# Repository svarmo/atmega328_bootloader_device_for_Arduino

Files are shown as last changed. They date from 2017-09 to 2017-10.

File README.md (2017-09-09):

# Overview
The objective of this project is to create a fully functional Arduino Bootloader for the ATMega328 MCU.

This project will include all the sources to manufacture the programmer device, it includes the 3D printed model, the PCB manufacturing files as well as the source code for the device.

# License
This project is licenses under an MIT license, view attached file for more detail.

The MCU is works using Arduino and **HEAVILY** relies on code provided by Nick Gammon's Arduino_sketch code: https://github.com/nickgammon/arduino_sketches (Also MIT license)

All the hardware is designed by me and falls under **Open Hardware** spec so feel free to use, modify as you see fit.

## Special contributors
* Ricardo Rodriguez
* Nick Gammon

# Usage
TODO: Populate how to use

# Notes
At this point, a good write looks like this:

```
Started
Waiting 2 seconds
Attempting to enter ICSP programming mode ...ok

Getting signature
Processor = ATmega328P

*CURRENT FUSE VALUES*
Low_Fuse = E2
High_fuse = DA
Ext_Fuse = FD
Lock_Fuse = EF
Clock_Calibration_Fuse = 96

Using Lilypad 8 MHz loader.

Bootloader address = 7800
Bootloader length = 1932

*NEW FUSE VALUES*
Low_Fuse = E2
High_Fuse = DA
Ext_Fuse = 5
Lock_Fuse = 2F
Erasing chip ...
Writing bootloader ...
Written.
Verifying ...
No errors found.

Writing fuses ...

*CURRENT FUSE VALUES*
Low_Fuse = E2
High_fuse = DA
Ext_Fuse = FD
Lock_Fuse = EF
Clock_Calibration_Fuse = 96

Done.
Programming mode off.
```

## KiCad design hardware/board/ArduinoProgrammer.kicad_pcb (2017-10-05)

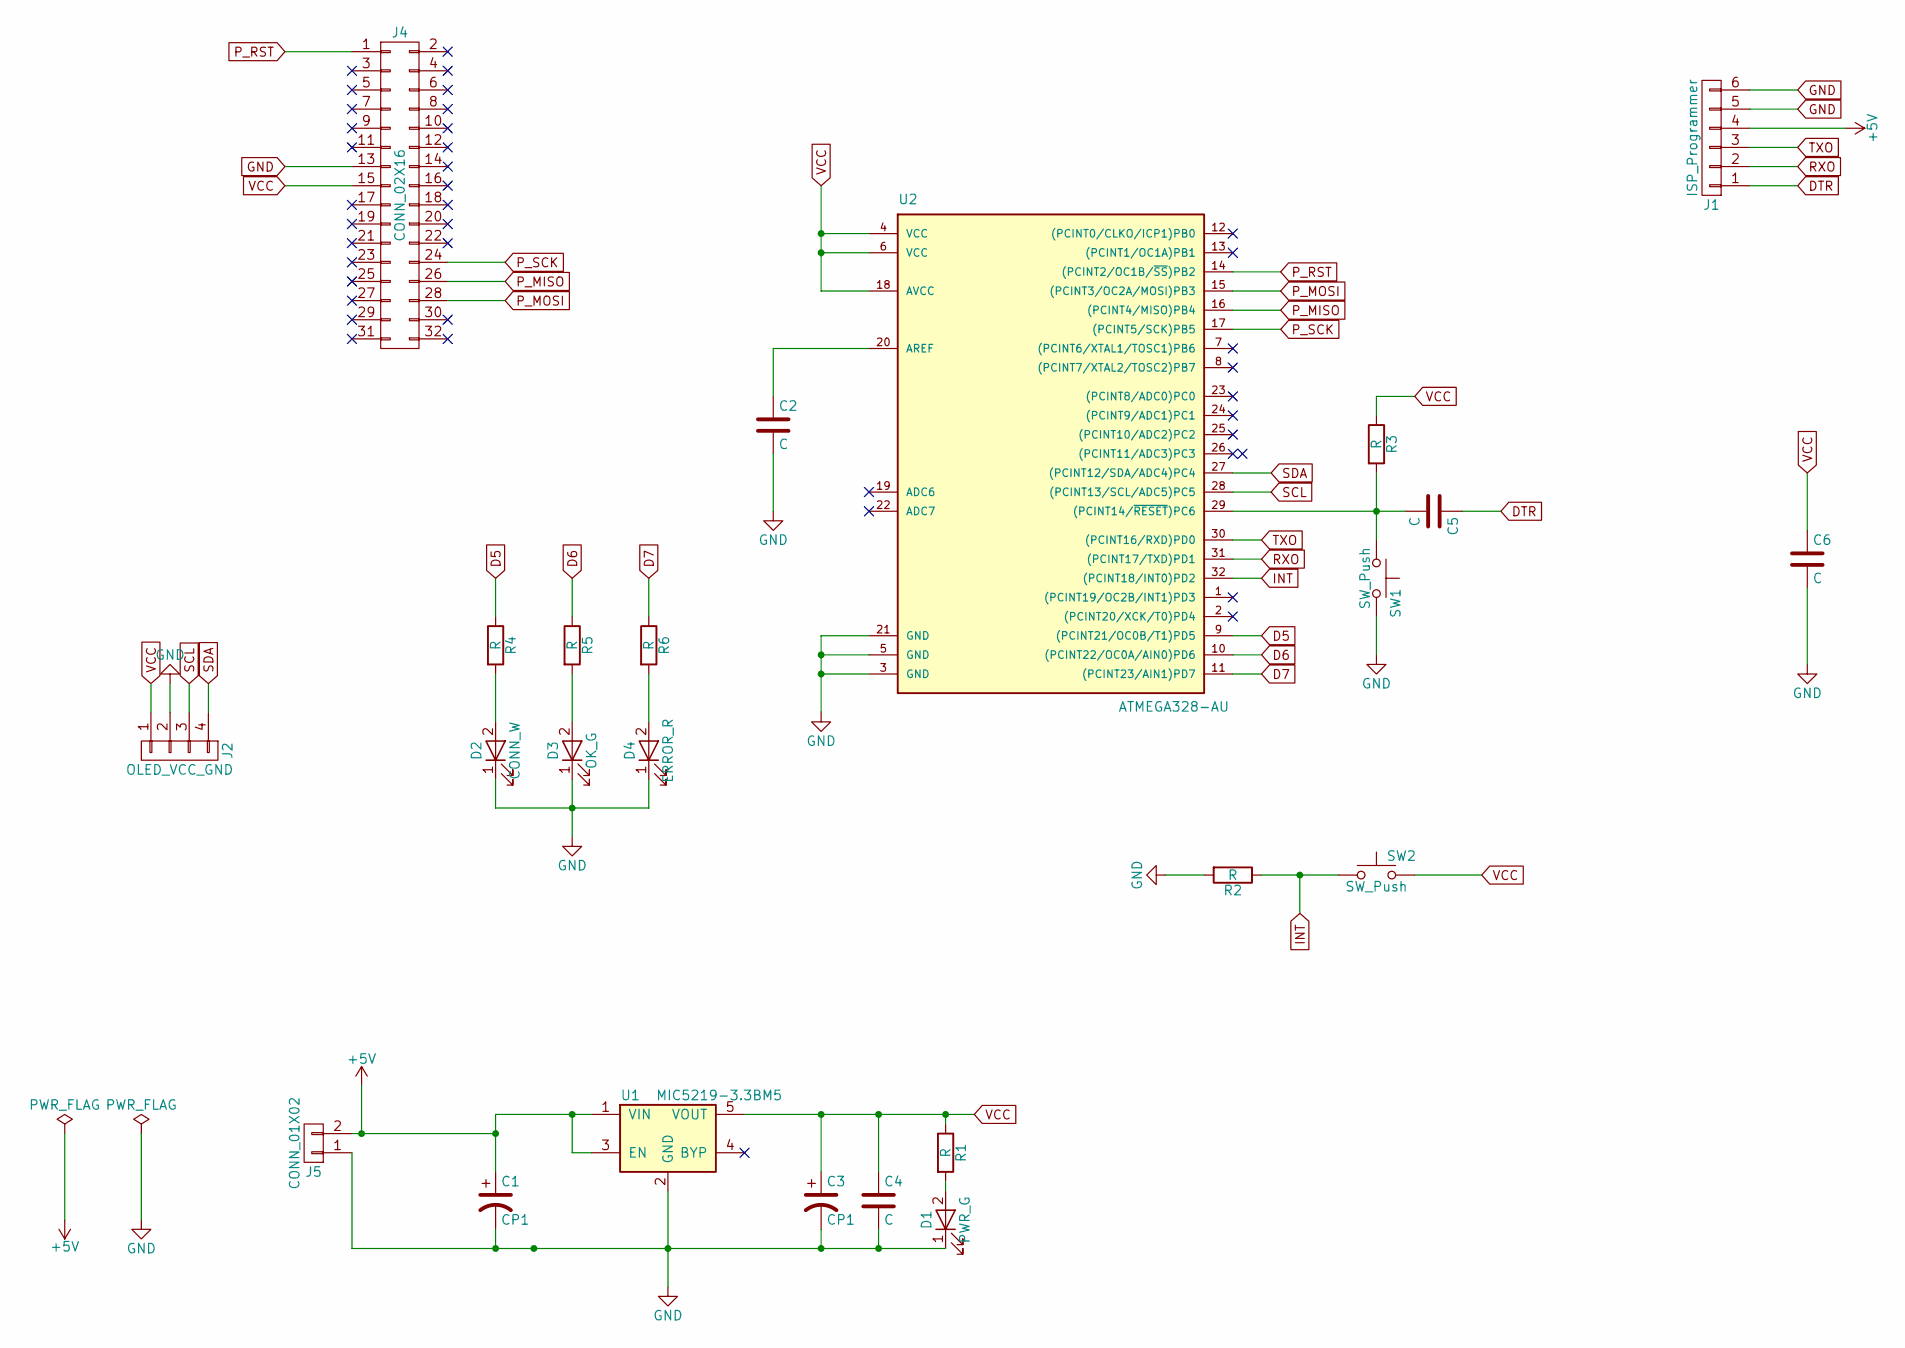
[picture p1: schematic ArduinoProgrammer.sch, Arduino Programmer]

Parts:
C1, C3: CP1; CP_Tantalum_Case-A_EIA-3216-18_Reflow
C2, C4, C5, C6: C; C_0805
D1: PWR_G; LED_0805
D2: CONN_W; LED_0805
D3: OK_G; LED_0805
D4: ERROR_R; LED_0805
J1: ISP_Programmer; Pin_Header_Straight_1x06_Pitch2.00mm
J2: OLED_VCC_GND
J4: CONN_02X16; ProgSocket
J5: CONN_01X02; Pin_Header_Straight_1x02_Pitch2.00mm
R1, R2, R3, R4, R5, R6: R; R_0805
SW1, SW2: SW_Push; SW_SPST_FSMSM
U1: MIC5219-3.3BM5; SOT-23-5
U2: ATMEGA328-AU; TQFP-32_7x7mm_Pitch0.8mm

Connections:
+5V: C1.1, J1.4, J5.2, U1.1 (VIN), U1.3 (EN)
D5: R4.1, U2.9 ((PCINT21/OC0B/T1)PD5)
D6: R5.1, U2.10 ((PCINT22/OC0A/AIN0)PD6)
D7: R6.1, U2.11 ((PCINT23/AIN1)PD7)
DTR: C5.1, J1.1
GND: C1.2, C2.2, C3.2, C4.2, C6.2, D1.1 (K), D2.1 (K), D3.1 (K), D4.1 (K), J1.5, J1.6, J2.2 (GND), J4.13, J5.1, R2.2, SW1.2, U1.2 (GND), U2.3 (GND), U2.5 (GND), U2.21 (GND)
INT: R2.1, SW2.1, U2.32 ((PCINT18/INT0)PD2)
unnamed: C2.1, U2.20 (AREF)
unnamed: C5.2, R3.2, SW1.1, U2.29 ((PCINT14/~RESET~)PC6)
unnamed: D1.2 (A), R1.2
unnamed: D2.2 (A), R4.2
unnamed: D3.2 (A), R5.2
unnamed: D4.2 (A), R6.2
P_MISO: J4.26, U2.16 ((PCINT4/MISO)PB4)
P_MOSI: J4.28, U2.15 ((PCINT3/OC2A/MOSI)PB3)
P_RST: J4.1, U2.14 ((PCINT2/OC1B/~SS~)PB2)
P_SCK: J4.24, U2.17 ((PCINT5/SCK)PB5)
RXO: J1.2, U2.31 ((PCINT17/TXD)PD1)
SCL: J2.3 (SCL), U2.28 ((PCINT13/SCL/ADC5)PC5)
SDA: J2.4 (SDA), U2.27 ((PCINT12/SDA/ADC4)PC4)
TXO: J1.3, U2.30 ((PCINT16/RXD)PD0)
VCC: C3.1, C4.1, C6.1, J2.1 (VCC), J4.15, R1.1, R3.1, SW2.2, U1.5 (VOUT), U2.4 (VCC), U2.6 (VCC), U2.18 (AVCC)

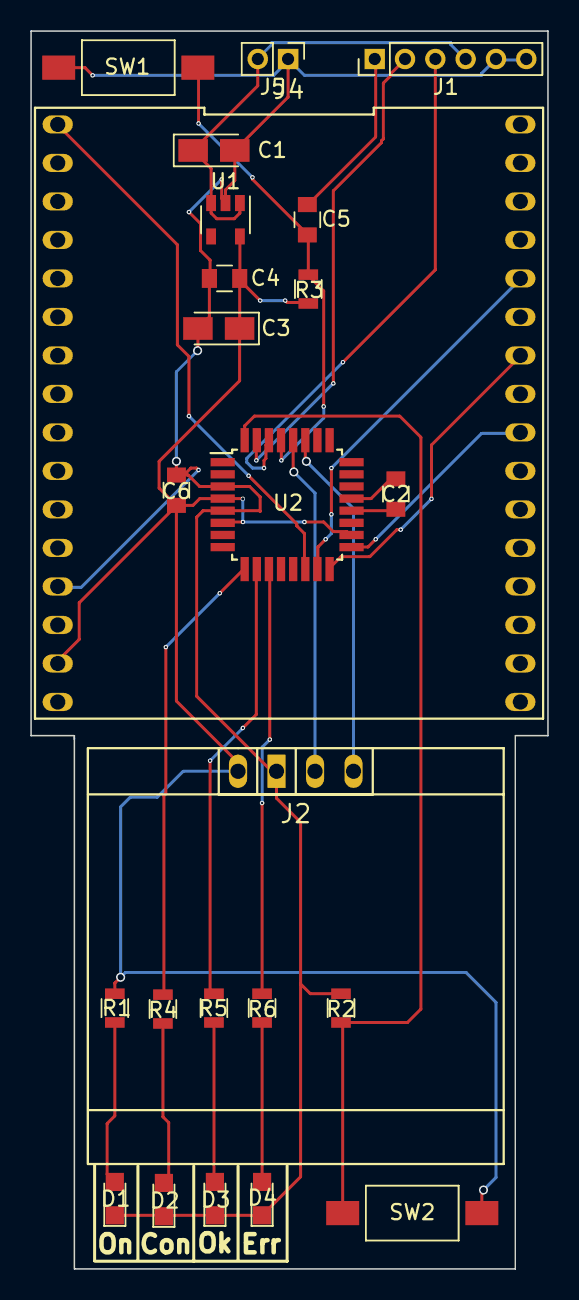
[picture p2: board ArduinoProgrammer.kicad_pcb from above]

Board: 2 copper layers, 34.1 x 81.7 mm, 24 parts (0 on the bottom side), 22 nets.

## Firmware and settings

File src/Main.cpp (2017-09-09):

/*
 *  Copyright (c) 2017 Svarmo
 */

#include "Arduino.h"
#include <SPI.h>
#include <avr/pgmspace.h>

#include "Signatures.h"
#include "General_Stuff.h"
#include "bootloader_lilypad328.h"
#include "bootloader_atmega328.h"

#define BAUD_RATE 9600
#define ENTER_PROGRAMMING_ATTEMPTS 50

#define CLOCKOUT 9
#define RESET 10
#define SCK 13
#define SELECT_BUTTON_PIN 2

/******************************/
// ICSP Utils
/******************************/
// programming commands to send via SPI to the chip
enum {
    progamEnable = 0xAC,

    // writes are preceded by progamEnable
    chipErase = 0x80,
    writeLockByte = 0xE0,
    writeLowFuseByte = 0xA0,
    writeHighFuseByte = 0xA8,
    writeExtendedFuseByte = 0xA4,
    //
    pollReady = 0xF0,

    programAcknowledge = 0x53,

    readSignatureByte = 0x30,
    readCalibrationByte = 0x38,
    readLowFuseByte = 0x50,       readLowFuseByteArg2 = 0x00,
    readExtendedFuseByte = 0x50,  readExtendedFuseByteArg2 = 0x08,
    readHighFuseByte = 0x58,      readHighFuseByteArg2 = 0x08,
    readLockByte = 0x58,          readLockByteArg2 = 0x00,
    //
    readProgramMemory = 0x20,
    writeProgramMemory = 0x4C,
    loadExtendedAddressByte = 0x4D,
    loadProgramMemory = 0x40
};  // end of enum

void clearPage(); // Declared in Programing_Utils

byte program(const byte b1, const byte b2 = 0, const byte b3 = 0, const byte b4 = 0);
byte program(const byte b1, const byte b2, const byte b3, const byte b4) {
    noInterrupts();

    SPI.transfer(b1);
    SPI.transfer(b2);
    SPI.transfer(b3);
    byte b = SPI.transfer(b4);

    interrupts();
    return b;
}

// poll the target device until it is ready to be programmed
void pollUntilReady() {
    if (currentSignature.timedWrites) {
        delay (10);  // at least 2 x WD_FLASH which is 4.5 mS
    } else {
        while ((program(pollReady) & 1) == 1) {}  // wait till ready
    }
}

byte readFuse (const byte which) {
    switch (which) {
        case LOW_FUSE:         return program(readLowFuseByte, readLowFuseByteArg2);
        case HIGH_FUSE:        return program(readHighFuseByte, readHighFuseByteArg2);
        case EXT_FUSE:         return program(readExtendedFuseByte, readExtendedFuseByteArg2);
        case LOCK_FUSE:        return program(readLockByte, readLockByteArg2);
        case CALIBRATION_FUSE: return program(readCalibrationByte);
    }
   return 0;
}

const byte fuseCommands [4] = { writeLowFuseByte, writeHighFuseByte, writeExtendedFuseByte, writeLockByte };
void writeFuse(const byte newValue, const byte whichFuse) {
    if (newValue == 0) {
        return;  // ignore
    }

    program(progamEnable, fuseCommands[whichFuse], 0, newValue);
    pollUntilReady();
}

void stopProgramming() {
    digitalWrite(RESET, LOW);
    pinMode(RESET, INPUT);

    SPI.end();
    // turn off pull-ups, if any
    digitalWrite(SCK, LOW);
    digitalWrite(MOSI, LOW);
    digitalWrite(MISO, LOW);

    // set everything back to inputs
    pinMode(SCK, INPUT);
    pinMode(MOSI, INPUT);
    pinMode(MISO, INPUT);
    Serial.println (F("Programming mode off."));
}

bool startProgramming() {
    Serial.print(F("Attempting to enter ICSP programming mode ..."));

    pinMode(RESET, OUTPUT);
    digitalWrite(RESET, HIGH);  // ensure SS stays high for now
    SPI.begin();
    SPI.setClockDivider (SPI_CLOCK_DIV64);
    pinMode (SCK, OUTPUT);

    unsigned int timeout = 0;
    byte confirm;
    do {
        delay(100);     // regrouping pause
        noInterrupts(); // ensure SCK low
        digitalWrite(SCK, LOW);

        // then pulse reset, see page 309 of datasheet
        digitalWrite(RESET, HIGH);
        delayMicroseconds(10);  // pulse for at least 2 clock cycles
        digitalWrite(RESET, LOW);
        interrupts();
        delay(25);  // wait at least 20 mS
        noInterrupts();

        SPI.transfer(progamEnable);
        SPI.transfer(programAcknowledge);
        confirm = SPI.transfer(0);
        SPI.transfer(0);
        interrupts();

        if (confirm != programAcknowledge) {
            Serial.print (".");
            if (timeout++ >= ENTER_PROGRAMMING_ATTEMPTS) {
                Serial.println(F("\nFailed to enter programming mode. Double-check wiring!"));
                return false;
            }
        }
    } while (confirm != programAcknowledge);
    Serial.println(F("ok"));
    return true;
}

void eraseMemory() {
    program(progamEnable, chipErase);  // erase it
    delay(20);
    pollUntilReady();
    clearPage();  // clear temporary page
}

void writeFlash(unsigned long addr, const byte data) {
    byte high = (addr & 1) ? 0x08 : 0;  // set if high byte wanted
    addr >>= 1;  // turn into word address
    program (loadProgramMemory | high, 0, lowByte (addr), data);
}

byte readFlash(unsigned long addr) {
    byte high = (addr & 1) ? 0x08 : 0;  // set if high byte wanted
    addr >>= 1;  // turn into word address

    // set the extended (most significant) address byte if necessary
    byte MSB = (addr >> 16) & 0xFF;
    if (MSB != lastAddressMSB) {
        program (loadExtendedAddressByte, 0, MSB);
        lastAddressMSB = MSB;
    }  // end if different MSB

    return program (readProgramMemory | high, highByte (addr), lowByte (addr));
}

void readSignature(byte sig [3]) {
    for (byte i = 0; i < 3; i++) {
        sig [i] = program(readSignatureByte, 0, i);
    }

    // make sure extended address is zero to match lastAddressMSB variable
    program(loadExtendedAddressByte, 0, 0);
    lastAddressMSB = 0;
}

void initPins() {
    // set up 8 MHz timer on pin 9
    pinMode (CLOCKOUT, OUTPUT);
    // set up Timer 1
    TCCR1A = bit (COM1A0);              // toggle OC1A on Compare Match
    TCCR1B = bit (WGM12) | bit (CS10);  // CTC, no prescaling
    OCR1A =  0;                         // output every cycle
}

// commit page to flash memory
void commitPage (unsigned long addr, bool showMessage) {
    addr >>= 1;  // turn into word address

    // set the extended (most significant) address byte if necessary
    byte MSB = (addr >> 16) & 0xFF;
    if (MSB != lastAddressMSB) {
        program (loadExtendedAddressByte, 0, MSB);
        lastAddressMSB = MSB;
    }

    program(writeProgramMemory, highByte (addr), lowByte (addr));
    pollUntilReady();

    clearPage();  // clear ready for next page full
}


/******************************/
// Programing Utils stuff
/******************************/
// clear entire temporary page to 0xFF in case we don't write to all of it
void clearPage() {
    unsigned int len = currentSignature.pageSize;
    for (unsigned int i = 0; i < len; i++) {
        writeFlash(i, 0xFF);
    }
}  // end of clearPage

/************************/


// structure to hold signature and other relevant data about each bootloader
typedef struct {
    byte sig [3];                // chip signature
    unsigned long loaderStart;   // start address of bootloader (bytes)
    const byte * bootloader;     // address of bootloader hex data
    unsigned int loaderLength;   // length of bootloader hex data (bytes)
    byte lowFuse, highFuse, extFuse, lockByte;  // what to set the fuses, lock bits to.
} bootloaderType;

// see Atmega328 datasheet page 298
const bootloaderType bootloaders [] PROGMEM = {
    // Only known bootloaders are in this array.
    // If we support it at all, it will have a start address.
    // If not compiled into this particular version the bootloader address will be zero.

    // ATmega328P
    {
        { 0x1E, 0x95, 0x0F },
        0x7E00,               // start address
        atmega328_optiboot,   // loader image
        sizeof atmega328_optiboot,
        0xFF,         // fuse low byte: external clock, max start-up time
        0xDE,         // fuse high byte: SPI enable, boot into bootloader, 512 byte bootloader
        0x05,         // fuse extended byte: brown-out detection at 2.7V
        0x2F          // lock bits: SPM is not allowed to write to the Boot Loader section.
    },

};

bootloaderType currentBootloader;

void printFuseBytes() {
    byte lowFuseByte = readFuse(LOW_FUSE);
    byte highFuseByte = readFuse(HIGH_FUSE);
    byte extFuseByte = readFuse(EXT_FUSE);
    byte lockFuseByte = readFuse(LOCK_FUSE);
    byte calibrationFuseByte = readFuse(CALIBRATION_FUSE);

    Serial.println(F("\n*CURRENT FUSE VALUES*"));
    Serial.print(F("Low_Fuse = "));
    Serial.println(lowFuseByte, HEX);
    Serial.print(F("High_fuse = "));
    Serial.println(highFuseByte, HEX);
    Serial.print(F("Ext_Fuse = "));
    Serial.println(extFuseByte, HEX);
    Serial.print(F("Lock_Fuse = "));
    Serial.println(lockFuseByte, HEX);
    Serial.print(F("Clock_Calibration_Fuse = "));
    Serial.println(calibrationFuseByte, HEX);
    Serial.println();
}

// burn the bootloader to the target device
void writeBootloader() {
    bool foundBootloader = false;

    for (int j = 0; j < NUMITEMS (bootloaders); j++) {
        memcpy_P(&currentBootloader, &bootloaders [j], sizeof currentBootloader);

        if (memcmp(currentSignature.sig, currentBootloader.sig, sizeof currentSignature.sig) == 0) {
            foundBootloader = true;
            break;
        }  // end of signature found
    }  // end of for each signature

    if (!foundBootloader) {
        Serial.println(F("No bootloader support for this device."));
        return;
    }

    // if in the table, but with zero length, we need to enable a #define to use it.
    if (currentBootloader.loaderLength == 0) {
        Serial.println(F("Bootloader for this device is disabled, edit " __FILE__ " to enable it."));
        return;
    }

    byte lFuse = readFuse(LOW_FUSE);
    byte newlFuse = currentBootloader.lowFuse;
    byte newhFuse = currentBootloader.highFuse;
    byte newextFuse = currentBootloader.extFuse;
    byte newlockByte = currentBootloader.lockByte;

    unsigned long addr = currentBootloader.loaderStart;
    unsigned int  len = currentBootloader.loaderLength;
    unsigned long pagesize = currentSignature.pageSize;
    unsigned long pagemask = ~(pagesize - 1);
    const byte * bootloader = currentBootloader.bootloader;

    // Atmega328P or Atmega328
    if (currentBootloader.sig[0] == 0x1E && currentBootloader.sig[1] == 0x95
        && (currentBootloader.sig[2] == 0x0F || currentBootloader.sig[2] == 0x14)) {

        Serial.println(F("Using Lilypad 8 MHz loader."));
        bootloader = ATmegaBOOT_168_atmega328_pro_8MHz_hex;
        newlFuse = 0xE2;  // internal 8 MHz oscillator
        newhFuse = 0xDA;  //  2048 byte bootloader, SPI enabled
        addr = 0x7800;
        len = sizeof ATmegaBOOT_168_atmega328_pro_8MHz_hex;
    }  // end of being Atmega328P

    unsigned long oldPage = addr & pagemask;

    // Current Low Fuse does not match the bootloader's lowFuse setting, re-write it
    if (lFuse != newlFuse) {
        if ((lFuse & 0x80) == 0) {
            Serial.println(F("Clearing 'Divide clock by 8' fuse bit."));
        }

        Serial.print(F("Fixing low fuse setting ..."));
        // writeFuse (newlFuse, LOW_FUSE);
        delay (1000);
        stopProgramming ();  // latch fuse
        if (!startProgramming ()) {
            return;
        }
        delay (1000);
    }


    Serial.print(F("\nBootloader address = "));
    Serial.println(addr, HEX);
    Serial.print(F("Bootloader length = "));
    Serial.println(len);

    Serial.println(F("\n*NEW FUSE VALUES*"));
    Serial.print(F("Low_Fuse = "));
    Serial.println(newlFuse, HEX);
    Serial.print(F("High_Fuse = "));
    Serial.println(newhFuse, HEX);
    Serial.print(F("Ext_Fuse = "));
    Serial.println(newextFuse, HEX);
    Serial.print(F("Lock_Fuse = "));
    Serial.println(newlockByte, HEX);

    Serial.println(F("Erasing chip ..."));
    eraseMemory();
    Serial.println(F("Writing bootloader ..."));
    for (int i = 0; i < len; i += 2) {
        unsigned long thisPage = (addr + i) & pagemask;
        // page changed? commit old one
        if (thisPage != oldPage) {
            commitPage (oldPage, true);
            oldPage = thisPage;
        }
        writeFlash(addr + i, pgm_read_byte(bootloader + i));
        writeFlash(addr + i + 1, pgm_read_byte(bootloader + i + 1));
    }  // end while doing each word

    // commit final page
    commitPage(oldPage, true);
    Serial.println(F("Written."));
    // }  // end if programming

    Serial.println(F("Verifying ..."));

    // count errors
    unsigned int errors = 0;
    // check each byte
    for (int i = 0; i < len; i++) {
        byte found = readFlash (addr + i);
        byte expected = pgm_read_byte(bootloader + i);
        if (found != expected) {
            errors++;
        }  // end if error
    }  // end of for

    if (errors == 0) {
        Serial.println(F("No errors found."));
    } else {
        Serial.print(errors, DEC);
        Serial.println(F(" verification error(s)."));
        return;  // don't change fuses if errors
    }  // end if

    Serial.println(F("\nWriting fuses ..."));

    writeFuse(newlFuse, LOW_FUSE);
    writeFuse(newhFuse, HIGH_FUSE);
    writeFuse(newextFuse, EXT_FUSE);
    writeFuse(newlockByte, LOCK_FUSE);

    // confirm them
    printFuseBytes();
    Serial.println(F("Done."));
} // end of writeBootloader

void getSignature() {
    // TODO: Just make sure it matches the expected signature
    Serial.println(F("\nGetting signature"));
    byte sig[3];
    readSignature(sig);
    foundSig = -1;
    for (int j = 0; j < NUMITEMS (signatures); j++) {
        memcpy_P(&currentSignature, &signatures[j], sizeof currentSignature);

        if (memcmp(sig, currentSignature.sig, sizeof sig) == 0) {
            foundSig = j;
            Serial.print(F("Processor = "));
            Serial.println(currentSignature.desc);
            return;
        }
    }
    Serial.println(F("Unrecogized signature."));
}

// void bootloadingInterruptCallback() {
//     Serial.println("In Callback");
//     if (millis() - lastInterrupt >= 5000) {
//         lastInterrupt = millis();
//         executeBootloading = true;
//     }
// }

void programBootloader() {
    if (startProgramming()) {
        getSignature();
        printFuseBytes();

        // if we found a signature try to write a bootloader
        if (foundSig != -1) {
            writeBootloader();
        }
        stopProgramming();
    }
}

void setup() {
    Serial.begin (BAUD_RATE);
    Serial.println("Started");

    initPins();

    Serial.println("Waiting 2 seconds");
    delay(2000);
    programBootloader();
}

void loop() {}

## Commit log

2017-10-03 Added schem
    [ArduinoProgrammer.kicad_pcb, ArduinoProgrammer.sch]
2017-10-05 Added pcb circuit with OSx auto-route
    [ArduinoProgrammer.kicad_pcb, ArduinoProgrammer.sch]

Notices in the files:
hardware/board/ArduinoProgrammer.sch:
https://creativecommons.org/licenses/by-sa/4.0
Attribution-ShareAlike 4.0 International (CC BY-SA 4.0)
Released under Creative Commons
